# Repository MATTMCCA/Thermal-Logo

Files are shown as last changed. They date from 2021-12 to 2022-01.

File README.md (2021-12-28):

# Thermal Logo Business Card
A business card that "prints" the company logo on thermal paper.

Works with Arduino IDE to allow for easy experimentation. The HW design is based on Adafruit's *itsy bitsy* so I could benefit from there bootloader.

## Now on Rev_2

These Business Cards are not for sale/resale. They are strictly for networking, and **Thermal Printer Shenanigans**. Please do-not misuse the design or business cards, any injury that occurs as a result of malintent or negligence, I am not responsible for. 

#### This device will get hot enough to activate thermal paper, please, *business responsibly*. 

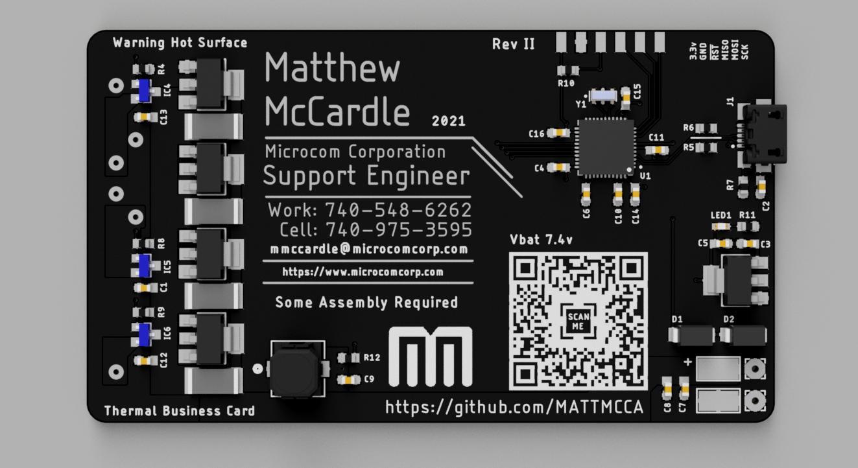
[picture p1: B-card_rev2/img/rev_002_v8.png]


### Borrowed works maintain original license.

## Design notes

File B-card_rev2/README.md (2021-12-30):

# Thermal Logo Business Card
A business card that "prints" the company logo on thermal paper.

# Possible Issues with the Design
- Load resistors might need to be smaller to increase current draw. [piggyback 11's on the vreg channels to get 1.88A, or x2 2.27A, x3 2.72A (*for testing*)]
- IDK if the bootloader I plan on using is compatible with the MCU I nabbed from digikey, I think it will but there is a chance it wont.
- The high current part of the PCB might get a wee bit warm.
- IDK about the switch I picked.
- Still no power switch
- No safety measures in place.
- Publishing my contact details online... not too bright... but oh well.
- My confidence level is 65% (kinda high, its usually only 40%) [Lower Now... 40%, I got cocky]
- **OH WOW!, I should have inverted the QR code.....** [fixed on PCB] 
- **OH WOW!, the usb is wired wrong, so... that stinks...** (I'll just nix the resistors and rewire to test) [fixed on PCB]

### Boards have been sent to fab, two assemblies worth of parts have been ordered.

Parts Came [12/29/2021], just wating on boards.

### Amazon Stuff

[Battery A](https://www.amazon.com/dp/B07DNCK7V2)

[Battery B](https://www.amazon.com/dp/B06ZY6J1P8)

[JST-SM 2-pin](https://www.amazon.com/dp/B01EJI8TQK)

[Fiberglass Tape](https://www.amazon.com/dp/B00823I7B6)

[36 gauge **NiCr** Wire](https://www.amazon.com/dp/B07CHTXZYW)

### Other

[0.4mmm Vias](https://www.voltera.io/store/consumables/rivets-0-4mm)

[Via Set Tool](https://www.voltera.io/store/consumables/rivet-tool)

#### Notes:
You cant really solder **NiCr**, its nickle and chrome, that chemistry would respond better to 'welding'. Since I don't have a tiny spot welder... yet.... I opted for permanent mechanical fasteners. Is this perfect? NO, dose it work? YES!

[Hmmm...](https://www.amazon.com/dp/B093SMWQ2Q) Amazon sells spot welders, might have to get one...

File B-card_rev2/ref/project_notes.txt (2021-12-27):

https://www.kanzan.de/en/products/thermal-papers/thermal-technology/thermal-paper-sensitivity
https://deepblueharp.blogspot.com/2018/04/wire-design-by-jim-whiteside.html#
https://www.printingforless.com/Business-Card-Specifications.html

https://www.amazon.com/TapeCase-134-3-Fiberglass-PTFE-Tape/dp/B00823I7B6
https://www.amazon.com/Nichrome-80-Gauge-Resistance-Wire/dp/B07CHTXZYW

https://www.voltera.io/support/working-with-rivets
https://www.voltera.io/store/consumables/rivets-0-4mm
https://www.voltera.io/store/consumables/rivet-tool

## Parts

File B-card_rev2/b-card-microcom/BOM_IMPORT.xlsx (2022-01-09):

Qty | Value | Device | Package | Parts | Description | DIGI-KEY_PART_NUMBER
8 | 1uF | C-EUC0603 | C0603 | C1, C3, C5, C7, C8, C10, C12, C13 | CAPACITOR, European symbol | 399-3118-1-ND
6 | 100k | R-US_R0603 | R0603 | R4, R7, R8, R9, R10, R12 | RESISTOR, American symbol | RMCF0603FT100KCT-ND
6 | WIREPADSMD1,27-254 | WIREPADSMD1,27-254 | SMD1,27-2,54 | PAD5, PAD6, PAD7, PAD8, PAD9, PAD10 | Wire PAD connect wire on PCB | NOT A REAL PART
4 | 5.6 | R-US_R2512 | R2512 | R1, R2, R3, R13 | RESISTOR, American symbol | CPA25Q5.6CT-ND
4 | AZ1117IH-5.0 | LD117ASTR | SOT223 | IC1, IC2, IC3, IC8 | Low drop fixed and adjustable positive voltage regulators 1 A | AZ1117IH-5.0TRG1DICT-ND
3 | DMN2041L-7 | DS31126 | SOT23 | IC4, IC5, IC6 |  | DMN2041L-7DICT-ND
7 | 0.1uF | C-EUC0603 | C0603 | C2, C9, C14, C15, C16, C6, C4 | CAPACITOR, European symbol | 1276-1006-1-ND
2 | 22 | R-US_R0603 | R0603 | R5, R6 | RESISTOR, American symbol | RMCF0603FT22R0CT-ND
2 | LSM115JE3 | DIODE-DO214BA | DO214BA | D1, D2 | DIODE | LSM115JE3/TR13CT-ND
2 | WIREPAD2,54/0,9 | WIREPAD2,54/0,9 | 2,54/0,9 | PAD2, PAD3 | Wire PAD connect wire on PCB | NOT A REAL PART
2 | WIREPADSMD5-2,5 | WIREPADSMD5-2,5 | 5-2,5 | PAD1, PAD4 | Wire PAD connect wire on PCB | NOT A REAL PART
1 | GREEN | LEDSML0603 | SML0603 | LED1 | LED | 732-12017-1-ND
1 | 10118192-0002LF | 10118192-0002LF | AMPHENOL_10118192-0002LF | J1 | USB - micro B USB 2.0 Receptacle Connector 5 Position Surface Mount, Right Angle | 609-5379-1-ND
1 | 10uF | C-EUC0603 | C0603 | C11 | CAPACITOR, European symbol | 1276-1038-1-ND
1 | 600 | R-US_R0603 | R0603 | R11 | RESISTOR, American symbol | 738-RMCF0603FG604RCT-ND
1 | ATMEGA32U4-MU | ATMEGA32U4-MU | QFN50P700X700X100-45N | U1 | 8-bit Microcontrollers - MCU AVR USB 32K FLASH INDUSTRIA | ATMEGA32U4-MU-ND
1 | AZ1117IH-3.3 | LD117ASTR | SOT223 | IC7 | Low drop fixed and adjustable positive voltage regulators 1 A | AZ1117IH-3.3TRG1DICT-ND
1 | B3AL-1000P | B3AL-1000P | SW_B3AL_OMR | SW1 |  | SW1216CT-ND
1 | CSTNE8M00GH5C000R0 | CSTNE8M00GH5C000R0 | OSC_CSTNE8M00GH5C000R0 | Y1 | 8MHz Ceramic Resonator Built in Capacitor 33pF ±0.13% 40 Ohms -40°C ~ 125°C Surface Mount | 490-17961-1-ND, ALT=50-ECS-CTE-8.00-10-CT-ND
1 | HOT_WIRE | HOT_WIRE | LAYOUT_A | NICR1 |  | NOT A REAL PART

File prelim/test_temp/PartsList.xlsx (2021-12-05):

REF | Val | Part Number | Quantity | Supplier | URL
R1 | 10k | RMCF0603JT10K0CT-ND | 1 | Digikey | https://www.digikey.com/en/products/detail/stackpole-electronics-inc/RMCF0603JT10K0/1758104
R2 | 18 | A121160CT-ND | 1 | Digikey | https://www.digikey.com/en/products/detail/te-connectivity-passive-product/352218RJT/5245011
R3 | 10k | RMCF0603JT10K0CT-ND | 1 | Digikey | https://www.digikey.com/en/products/detail/stackpole-electronics-inc/RMCF0603JT10K0/1758104
R4 | 18 | A121160CT-ND | 1 | Digikey | https://www.digikey.com/en/products/detail/te-connectivity-passive-product/352218RJT/5245011
R5 | 10k | RMCF0603JT10K0CT-ND | 1 | Digikey | https://www.digikey.com/en/products/detail/stackpole-electronics-inc/RMCF0603JT10K0/1758104
R6 | 18 | A121160CT-ND | 1 | Digikey | https://www.digikey.com/en/products/detail/te-connectivity-passive-product/352218RJT/5245011
IC1 | DMN3150 | DMN3150LDICT-ND | 1 | Digikey | https://www.digikey.com/en/products/detail/diodes-incorporated/DMN3150L-7/1774198
IC2 | 74HCS125 | 296-SN74HCS125PWRCT-ND | 1 | Digikey | https://www.digikey.com/en/products/detail/texas-instruments/SN74HCS125PWR/12642216
IC3 | DMN3150 | DMN3150LDICT-ND | 1 | Digikey | https://www.digikey.com/en/products/detail/diodes-incorporated/DMN3150L-7/1774198
IC4 | DMN3150 | DMN3150LDICT-ND | 1 | Digikey | https://www.digikey.com/en/products/detail/diodes-incorporated/DMN3150L-7/1774198
C1 | .1uf | 732-13187-1-ND | 1 | Digikey | https://www.digikey.com/en/products/detail/w%C3%BCrth-elektronik/885382206004/9816342
C2 | .1uf | 732-13187-1-ND | 1 | Digikey | https://www.digikey.com/en/products/detail/w%C3%BCrth-elektronik/885382206004/9816342
SV1 | 8pos header | 1528-2923-ND | 0 | Digikey | https://www.digikey.com/en/products/detail/adafruit-industries-llc/4151/10123802
 | Nichrome 80, 36AWG |  | 1 | amazon | https://www.amazon.com/Nichrome-80-Gauge-Resistance-Wire/dp/B07CHTXZYW
 | PTFE Glass Cloth Tape |  | 1 | amazon | https://www.amazon.com/TapeCase-134-3-Fiberglass-PTFE-Tape/dp/B00823I7B6
 | 0.4mm copper rivets, drill .7mm | 1000283 | 1 | voltera.io | https://www.voltera.io/store/consumables/rivets-0-4mm
 | rivet press tool | 1000288 | 1 | voltera.io | https://www.voltera.io/store/consumables/rivet-tool

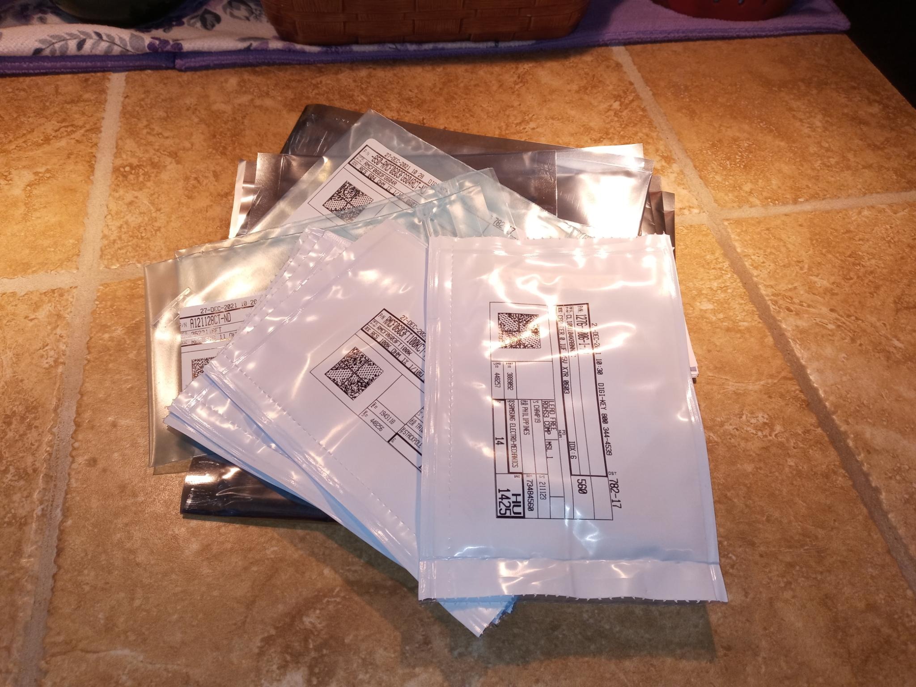
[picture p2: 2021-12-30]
B-card_rev2/img/tests/parts.png

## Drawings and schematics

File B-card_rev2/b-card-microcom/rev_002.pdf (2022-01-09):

# GND +3V³

A

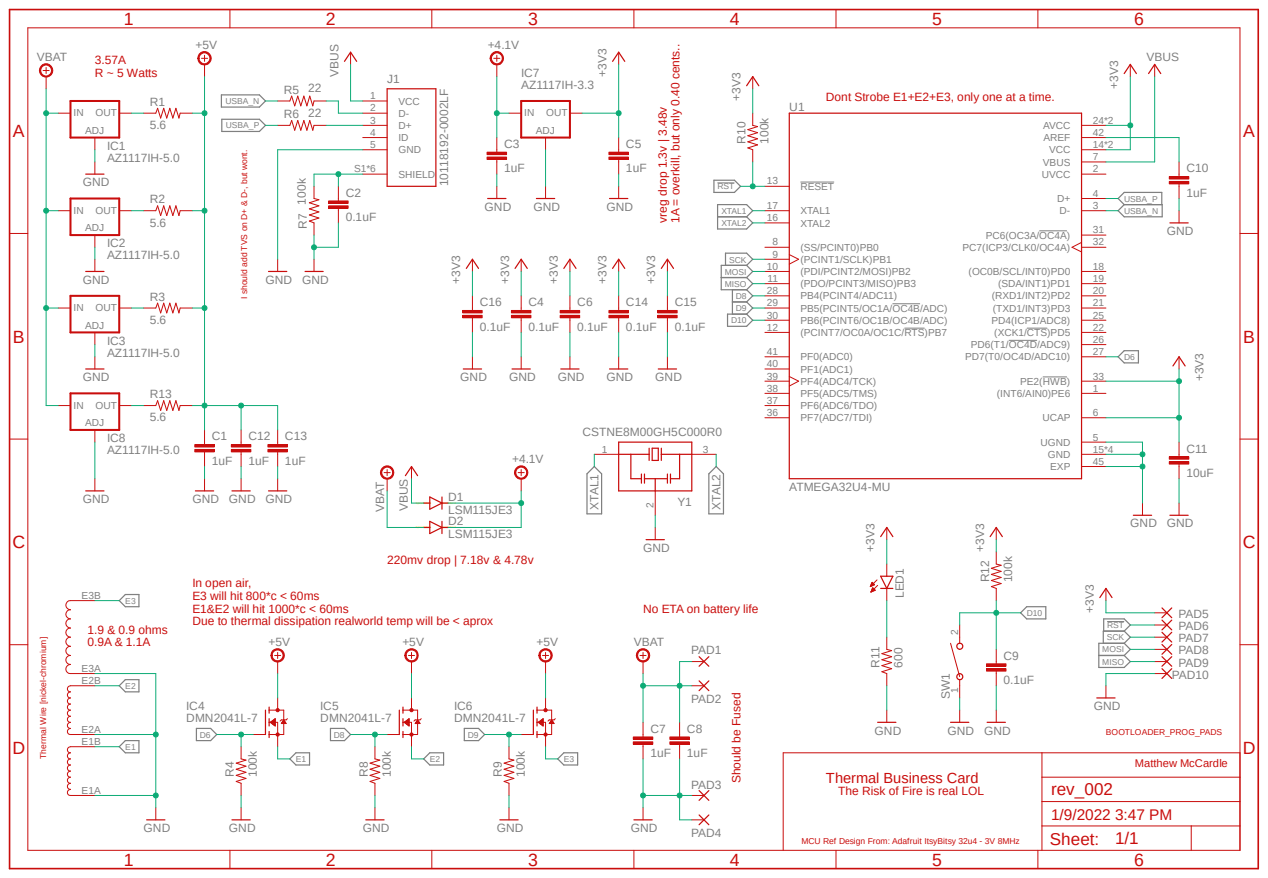
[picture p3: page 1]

Dont Strobe E1+E2+E3, only one at a time.

MCU Ref Design From: Adafruit ItsyBitsy 32u4 - 3V 8MHz I should add TVS on D⁺ & D⁻, but wont.

In open air,
E3 will hit 800*c < 60ms
E1&E2 will hit 1000*c < 60ms
Due to thermal dissipation realworld temp will be < aprox

No ETA on battery life

Matthew McCardle Thermal Wire [nickel-chromium]

Thermal Business Card The Risk of Fire is real LOL

Sheet: 1/1

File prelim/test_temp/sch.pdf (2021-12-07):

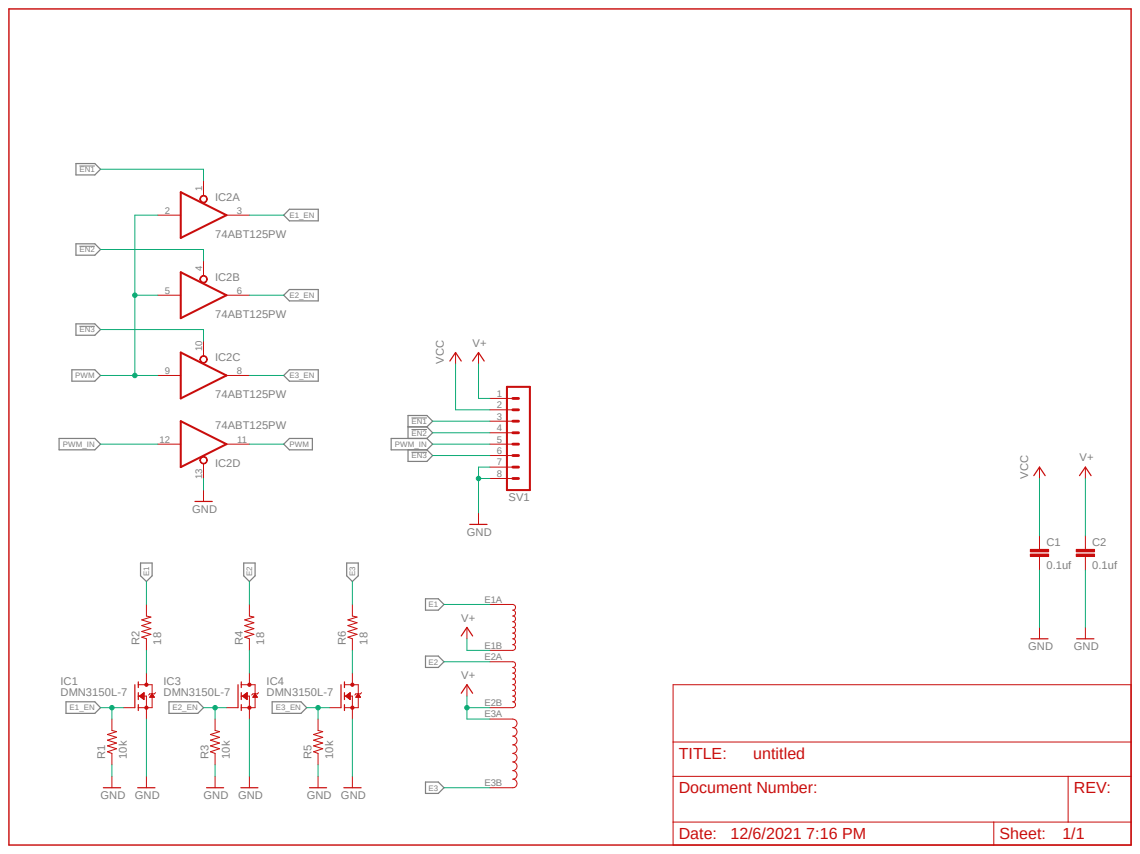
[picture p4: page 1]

Document Number: | REV:

Date: 12/6/2021 7:16 PM | Sheet: 1/1

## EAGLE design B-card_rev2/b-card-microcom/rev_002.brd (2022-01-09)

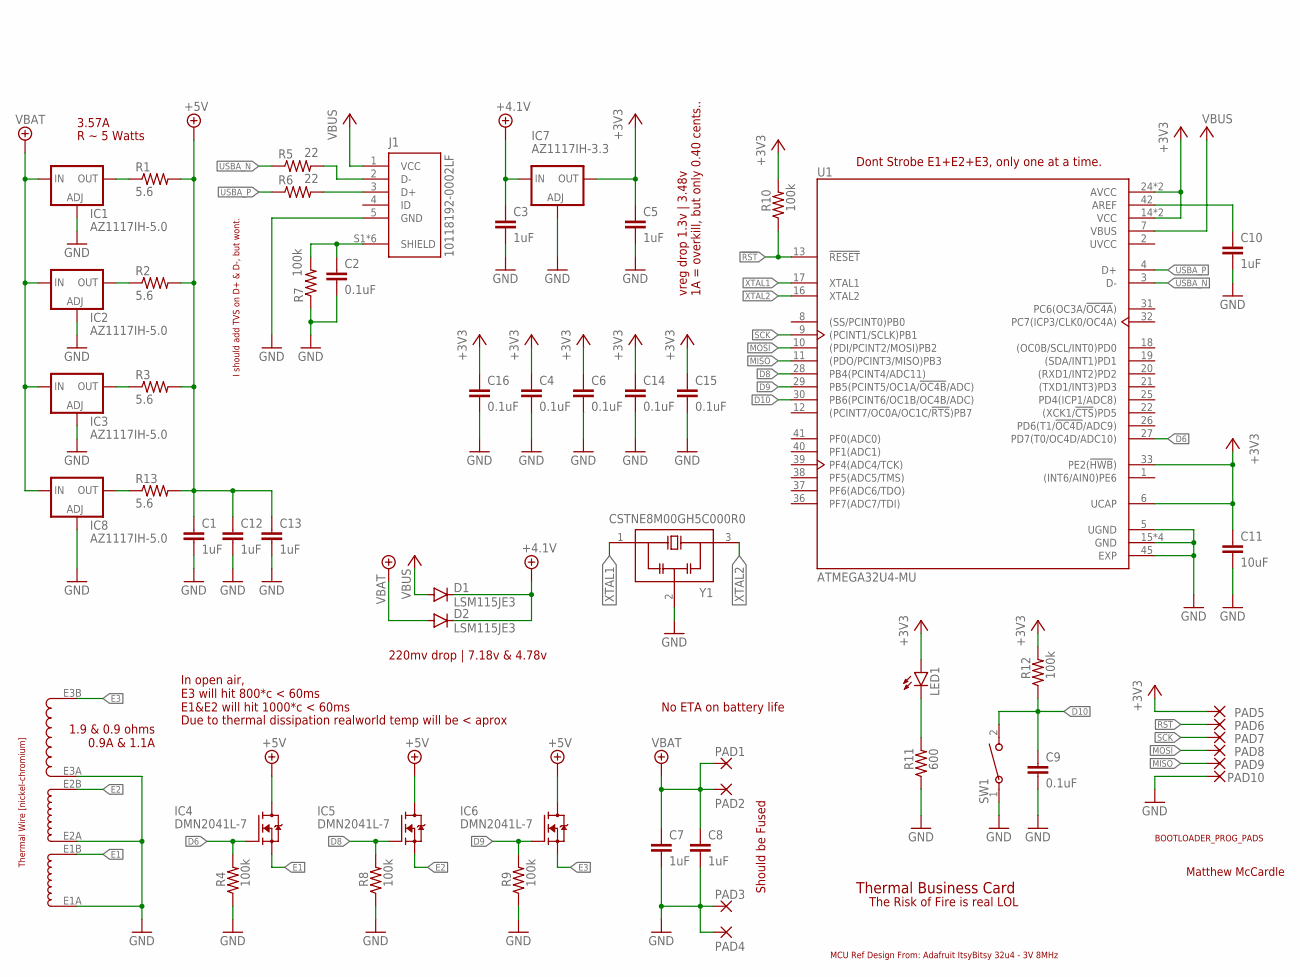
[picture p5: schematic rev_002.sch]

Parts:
C1, C3, C5, C7, C8, C10, C12, C13: 1uF; C0603
C2, C4, C6, C9, C14, C15, C16: 0.1uF; C0603
C11: 10uF; C0603
D1, D2: LSM115JE3; DO214BA
IC1, IC2, IC3, IC8: AZ1117IH-5.0; SOT223
IC4, IC5, IC6: DMN2041L-7; SOT23
IC7: AZ1117IH-3.3; SOT223
J1: 10118192-0002LF; AMPHENOL_10118192-0002LF
LED1: LEDSML0603; SML0603
NICR1: HOT_WIRE; LAYOUT_A
PAD1, PAD4: WIREPADSMD5-2,5; 5-2,5
PAD2, PAD3: WIREPAD2,54/0,9; 2,54/0,9
PAD5, PAD6, PAD7, PAD8, PAD9, PAD10: WIREPADSMD1,27-254; SMD1,27-2,54
R1, R2, R3, R13: 5.6; R2512
R4, R7, R8, R9, R10, R12: 100k; R0603
R5, R6: 22; R0603
R11: 600; R0603
SW1: B3AL-1000P; SW_B3AL_OMR
U1: ATMEGA32U4-MU; QFN50P700X700X100-45N
Y1: CSTNE8M00GH5C000R0; OSC_CSTNE8M00GH5C000R0

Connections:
!RST: PAD6.1, R10.1, U1.13 (!RESET!)
+3V3: C4.1, C5.1, C6.1, C11.1, C14.1, C15.1, C16.1, IC7.2 (OUT), IC7.4 (OUT), LED1.A, PAD5.1, R10.2, R12.2, U1.6 (UCAP), U1.14 (VCC), U1.24 (AVCC), U1.33 (PE2(!HWB!)), U1.34 (VCC), U1.44 (AVCC)
+4.1V: C3.1, D1.C, D2.C, IC7.3 (IN)
+5V: C1.1, C12.1, C13.1, IC4.D, IC5.D, IC6.D, R1.2, R2.2, R3.2, R13.2
+8V: C7.1, C8.1, D2.A, IC1.3 (IN), IC2.3 (IN), IC3.3 (IN), IC8.3 (IN), PAD1.1, PAD2.1
D6: IC4.G, R4.2, U1.27 (PD7(T0/OC4D/ADC10))
D8: IC5.G, R8.2, U1.28 (PB4(PCINT4/ADC11))
D9: IC6.G, R9.2, U1.29 (PB5(PCINT5/OC1A/!OC4B!/ADC))
D10: C9.1, R12.1, SW1.2, U1.30 (PB6(PCINT6/OC1B/OC4B/ADC))
E1: IC4.S, NICR1.E1B
E2: IC5.S, NICR1.E2B
E3: IC6.S, NICR1.E3B
GND: C1.2, C2.2, C3.2, C4.2, C5.2, C6.2, C7.2, C8.2, C9.2, C10.2, C11.2, C12.2, C13.2, C14.2, C15.2, C16.2, IC1.1 (ADJ), IC2.1 (ADJ), IC3.1 (ADJ), IC7.1 (ADJ), IC8.1 (ADJ), J1.5 (GND), NICR1.E1A, NICR1.E2A, NICR1.E3A, PAD3.1, PAD4.1, PAD10.1, R4.1, R7.1, R8.1, R9.1, R11.1, SW1.1, U1.5 (UGND), U1.15 (GND), U1.23 (GND), U1.35 (GND), U1.43 (GND), U1.45 (EXP), Y1.2 (GND)
MISO: PAD9.1, U1.11 ((PDO/PCINT3/MISO)PB3)
MOSI: PAD8.1, U1.10 ((PDI/PCINT2/MOSI)PB2)
unnamed: IC8.2 (OUT), IC8.4 (OUT), R13.1
unnamed: C10.1, U1.42 (AREF)
unnamed: C2.1, J1.S1 (SHIELD), J1.S2 (SHIELD), J1.S3 (SHIELD), J1.S4 (SHIELD), J1.S5 (SHIELD), J1.S6 (SHIELD), R7.2
unnamed: LED1.C, R11.2
unnamed: IC3.2 (OUT), IC3.4 (OUT), R3.1
unnamed: IC2.2 (OUT), IC2.4 (OUT), R2.1
unnamed: IC1.2 (OUT), IC1.4 (OUT), R1.1
SCK: PAD7.1, U1.9 ((PCINT1/SCLK)PB1)
USBA_N: R5.1, U1.3 (D-)
USBA_P: R6.1, U1.4 (D+)
USBB_N: J1.2 (D-), R5.2
USBB_P: J1.3 (D+), R6.2
UVCC: U1.2 (UVCC)
VBUS: D1.A, J1.1 (VCC), U1.7 (VBUS)
XTAL1: U1.17 (XTAL1), Y1.1 (IN)
XTAL2: U1.16 (XTAL2), Y1.3 (OUT)

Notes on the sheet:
MCU Ref Design From: Adafruit ItsyBitsy 32u4 - 3V 8MHz
I should add TVS on D+ & D-, but wont.
BOOTLOADER_PROG_PADS
Matthew McCardle
Thermal Wire [nickel-chromium]
Thermal Business Card
3.57A
R ~ 5 Watts
220mv drop | 7.18v & 4.78v
vreg drop 1.3v | 3.48v 1A = overkill, but only 0.40 cents..
1.9 & 0.9 ohms 0.9A & 1.1A
Should be Fused
In open air, E3 will hit 800*c < 60ms E1&E2 will hit 1000*c < 60ms
Due to thermal dissipation realworld temp will be < aprox
The Risk of Fire is real LOL
Dont Strobe E1+E2+E3, only one at a time.
No ETA on battery life

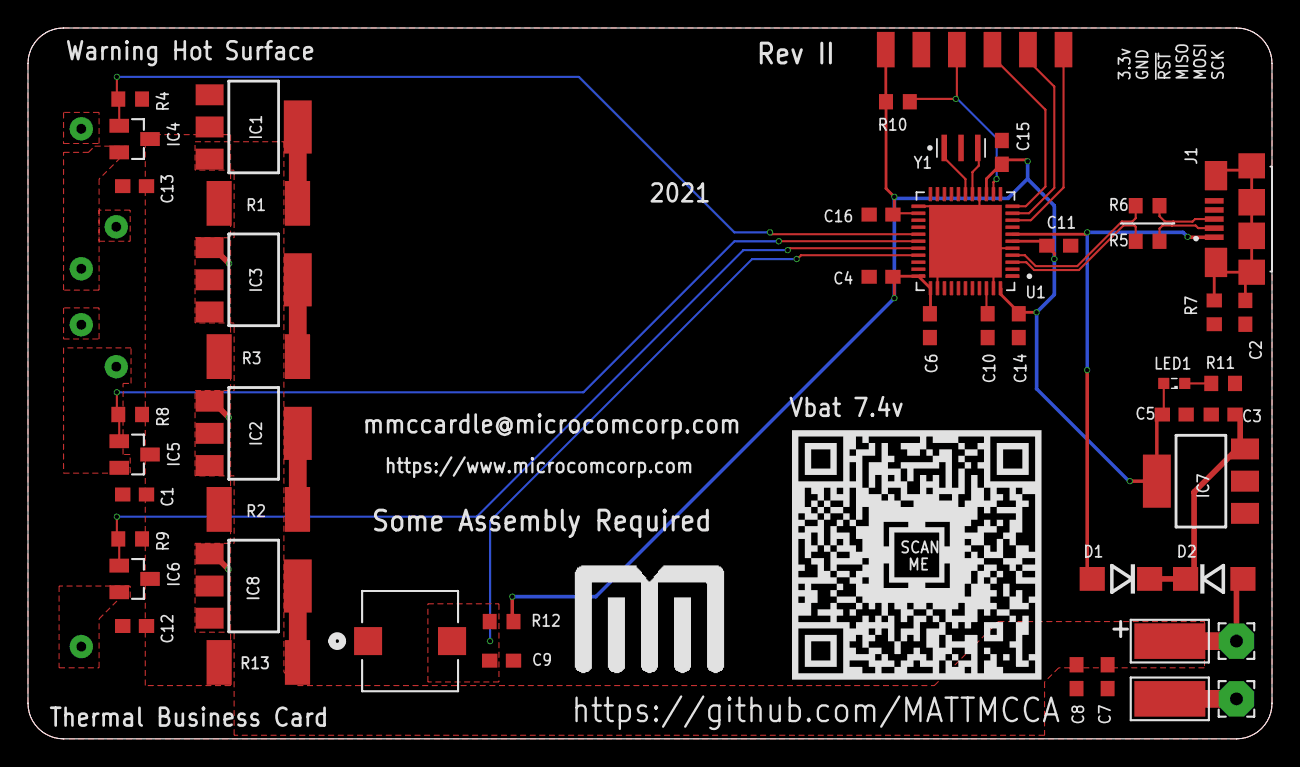
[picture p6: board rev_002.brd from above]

Board: 2 copper layers, 88.9 x 50.8 mm, 57 parts (0 on the bottom side), 30 nets.

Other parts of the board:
U$1: LINK_INV
U$2: MCOM

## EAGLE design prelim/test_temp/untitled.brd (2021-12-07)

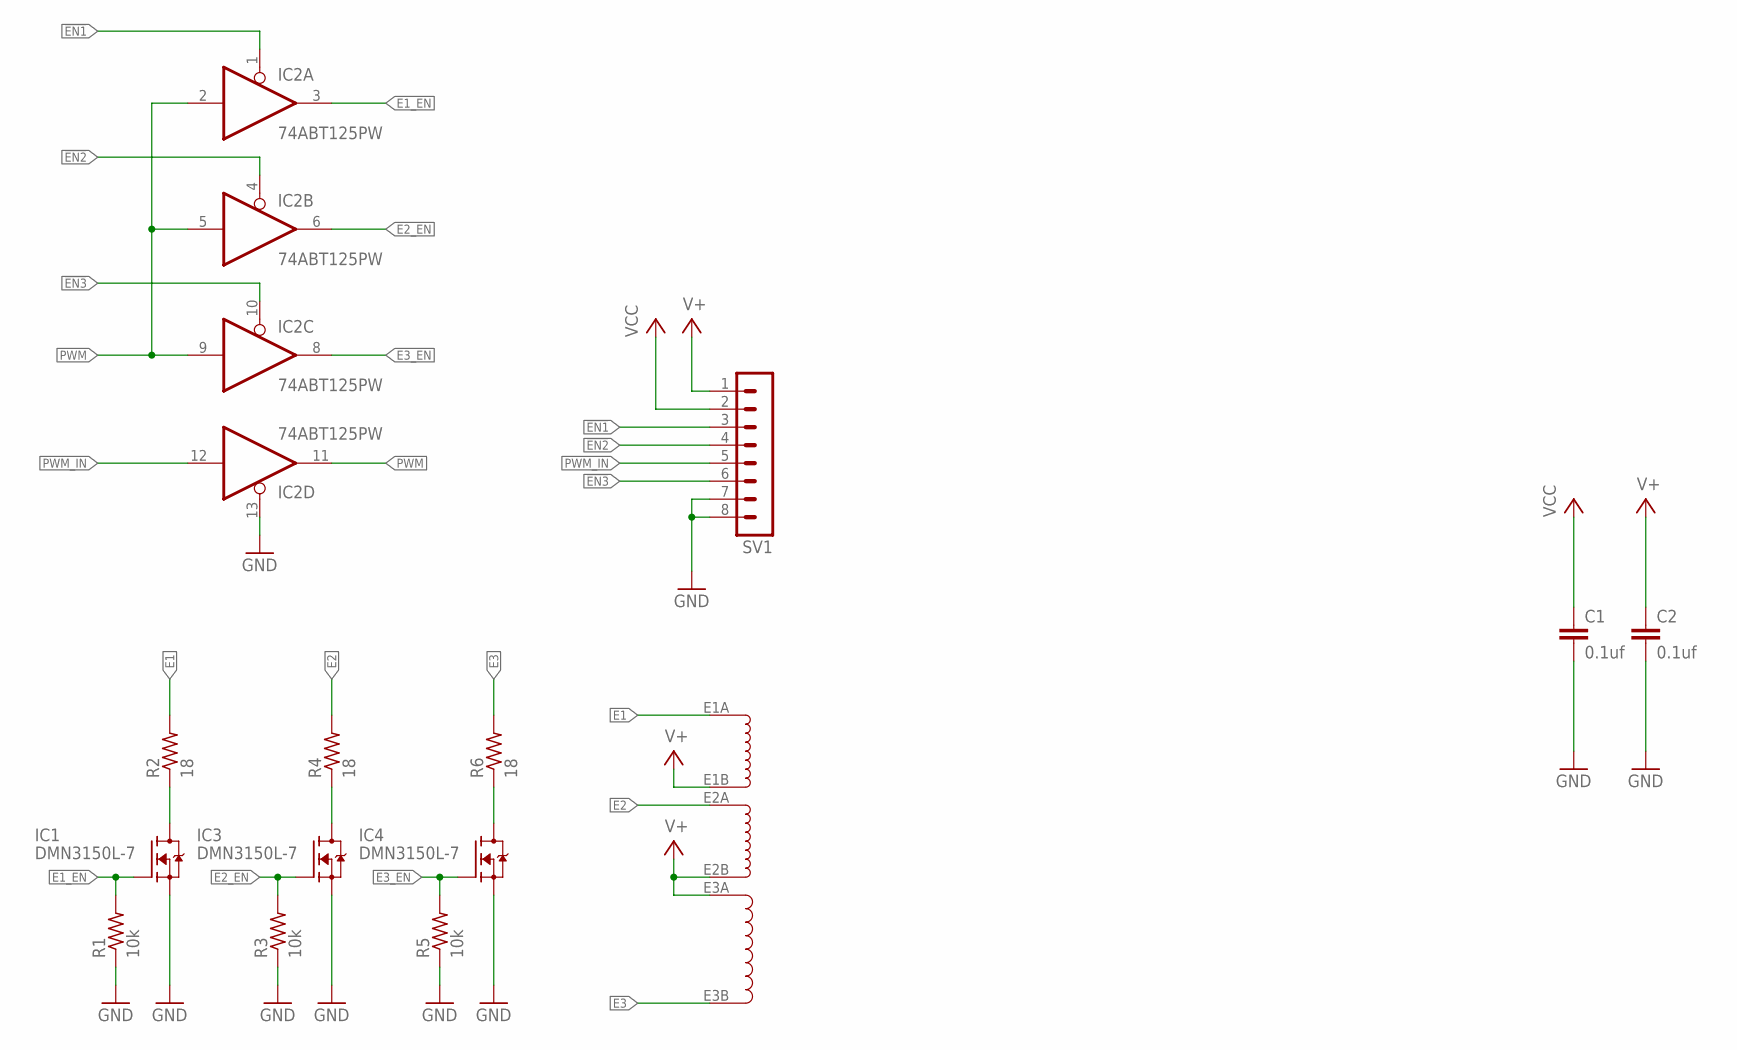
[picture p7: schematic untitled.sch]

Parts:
C1, C2: 0.1uf; C0603
IC1, IC3, IC4: DMN3150L-7; SOT23
IC2: 74ABT125PW; TSSOP14
NICR1: HOT_WIRE; LAYOUT_A
R1, R3, R5: 10k; R0603
R2, R4, R6: 18; R2512W
SV1: MA08-1

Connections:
!EN1: IC2.1 (OE), SV1.3
!EN2: IC2.4 (OE), SV1.4
!EN3: IC2.10 (OE), SV1.6
E1: NICR1.E1A, R2.2
E1_EN: IC1.G, IC2.3 (O), R1.2
E2: NICR1.E2A, R4.2
E2_EN: IC2.6 (O), IC3.G, R3.2
E3: NICR1.E3B, R6.2
E3_EN: IC2.8 (O), IC4.G, R5.2
GND: C1.2, C2.2, IC1.S, IC2.7 (GND), IC2.13 (OE), IC3.S, IC4.S, R1.1, R3.1, R5.1, SV1.7, SV1.8
unnamed: IC1.D, R2.1
unnamed: IC3.D, R4.1
unnamed: IC4.D, R6.1
PWM: IC2.2 (I), IC2.5 (I), IC2.9 (I), IC2.11 (O)
PWM_IN: IC2.12 (I), SV1.5
V+: C2.1, NICR1.E1B, NICR1.E2B, NICR1.E3A, SV1.1
VCC: C1.1, IC2.14 (VCC), SV1.2

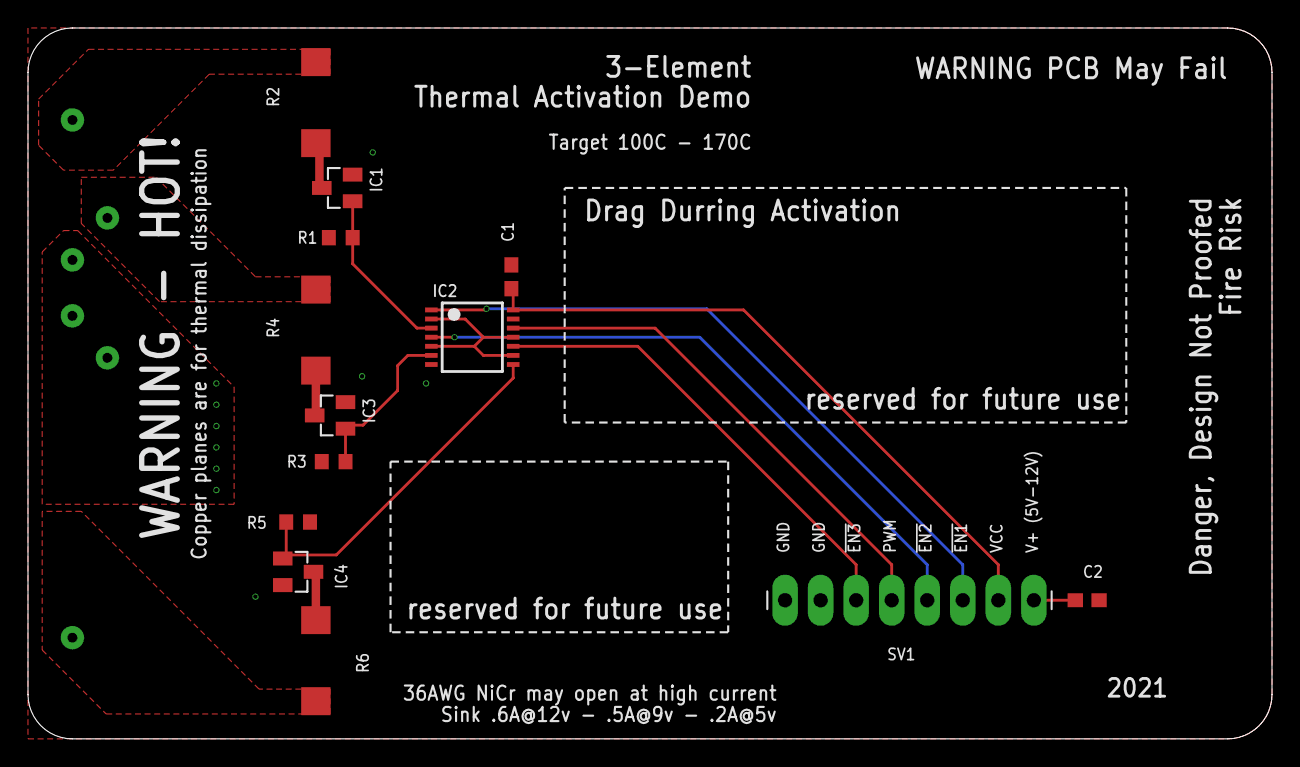
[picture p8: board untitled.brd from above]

Board: 2 copper layers, 88.9 x 50.8 mm, 14 parts (0 on the bottom side), 17 nets.

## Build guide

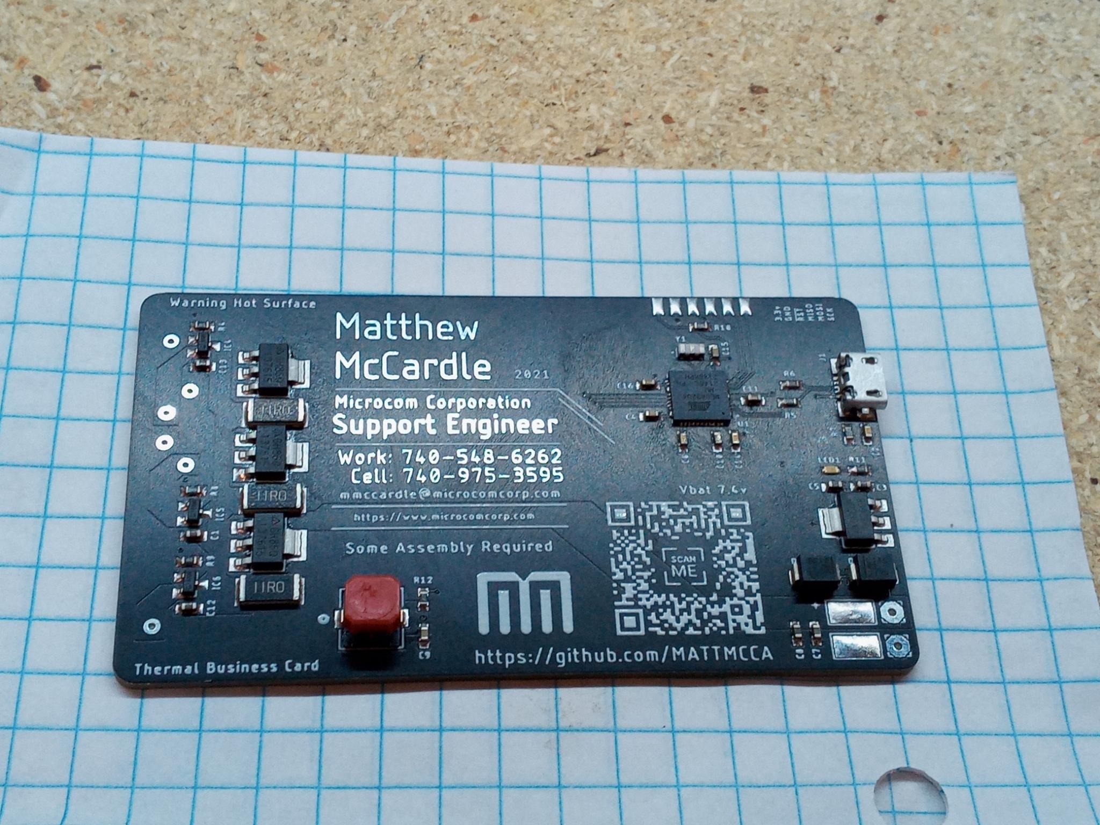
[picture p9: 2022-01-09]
B-card_rev2/img/build_001/002.png

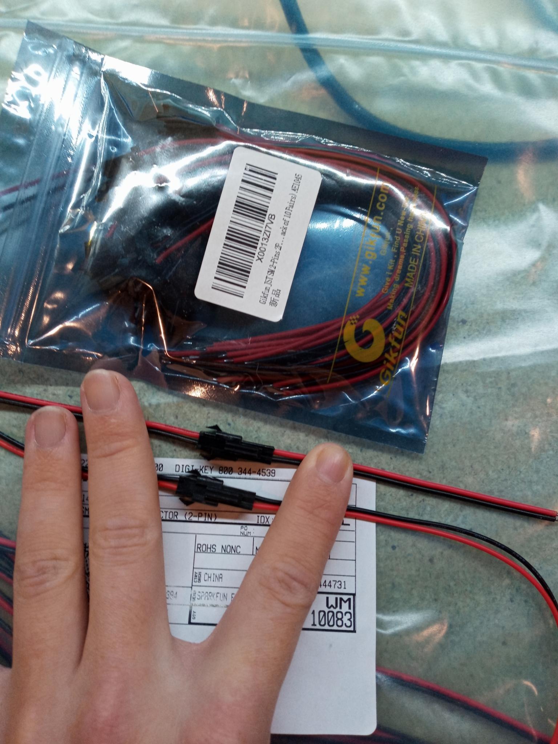
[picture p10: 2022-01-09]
B-card_rev2/img/build_001/004.png

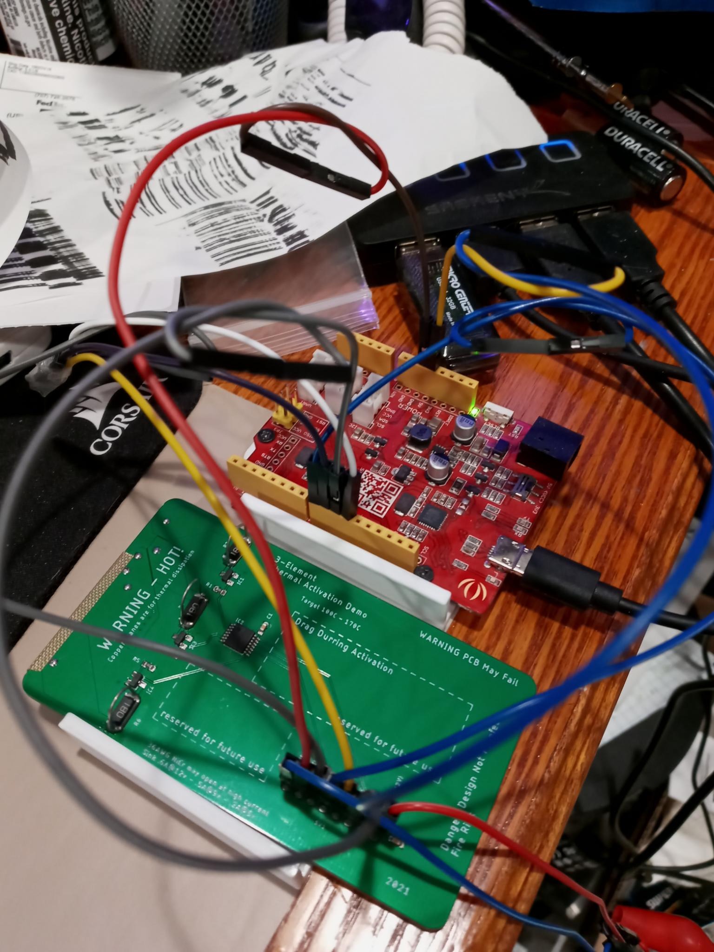
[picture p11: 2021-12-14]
B-card_rev2/img/tests/dirty_bench_setup.png

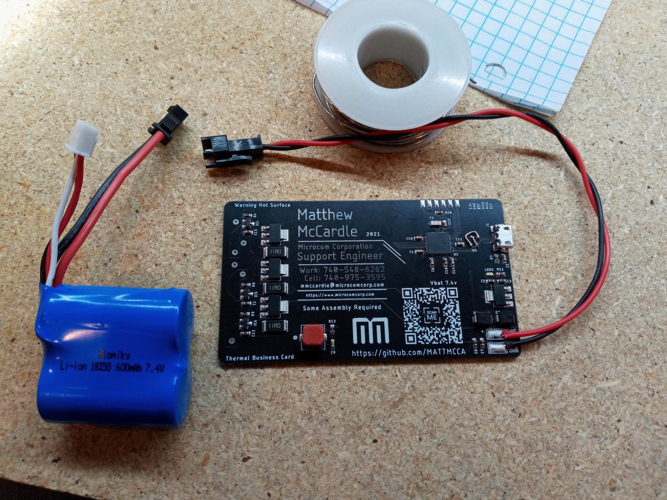
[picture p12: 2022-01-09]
B-card_rev2/img/build_001/001.png

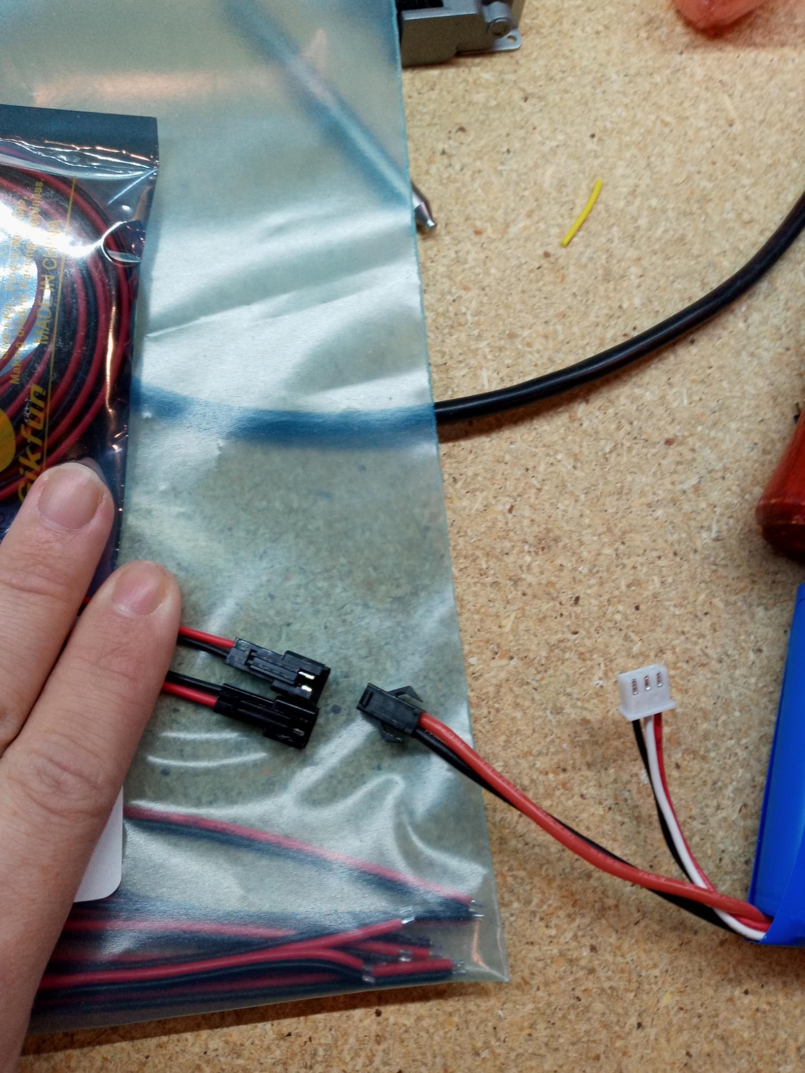
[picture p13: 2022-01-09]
B-card_rev2/img/build_001/003.png

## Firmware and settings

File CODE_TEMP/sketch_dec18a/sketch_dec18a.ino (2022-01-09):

/*
   Thermal Logo Business Card, Board REV_2 (Adafruit Itsy Bitsy 3v 8Mhz)
   MJM - 2021

   Warning! Hardware Will Get HOT!!

   but
      (•_•)
           ( •_•)>⌐■-■
                              (⌐■_■)  the firmware should stay kool.
*/

#define HOT    1
#define COLD   0
#define ACTIVE 0

#define COOL 0
#define HEAT 1

#define E2_OFFSET 4                         /* tune wire offset */

const int micro_pixle = 10;                 /* 20 upix per pix */
const int ms_delay    = 50;                 /* 10ms per E */

/* logo, replaces logic */
const int bmp_size  = 11;
const int bmp[3][bmp_size] = {
  {0, 1, 1, 1, 1, 0, 1, 1, 1, 1, 0},
  {0, 1, 0, 0, 0, 1, 0, 0, 0, 1, 0},
  {0, 1, 0, 1, 0, 1, 0, 1, 0, 1, 0}
};

/* IO deff */
const int TRIGGER = 10;
const int EN_1    = 6;
const int EN_2    = 8;
const int EN_3    = 9;

int SEQ[5][3]      = {
  // E1,   E2,   E3
  {COLD, COLD, COLD}, //state 3, E3
  {COLD, COLD, COLD}, //state 2, E2
  {COLD, COLD, COLD}, //state 3, E3
  {COLD, COLD, COLD}, //state 1, E1
  {COLD, COLD, COLD}  //state 3, E3
};

int cnt = 0, i = 0, e = 0, e2 = 0;

void state_seq(void);
void button_check(void);

void setup() {
  // put your setup code here, to run once:
  pinMode(TRIGGER,      INPUT);
  pinMode(EN_1,         OUTPUT);
  pinMode(EN_2,         OUTPUT);
  pinMode(EN_3,         OUTPUT);
  /****************************************************/
  digitalWrite(EN_1,    COLD); //off
  digitalWrite(EN_2,    COLD); //off
  digitalWrite(EN_3,    COLD); //off
  delay(100);
}

void loop() {
  // put your main code here, to run repeatedly:
  button_check();
  state_seq();

  for (i = 0; i < 5; i++) {
    digitalWrite(EN_1, SEQ[i][0]); /* E1 */
    digitalWrite(EN_2, SEQ[i][1]); /* E2 */
    digitalWrite(EN_3, SEQ[i][2]); /* E3 */
    delay(ms_delay);
  }
  cnt++;
}

void button_check(void) {
  /* loop while !active */
  while (digitalRead(TRIGGER) == !ACTIVE) {
    digitalWrite(EN_3, COLD);
    digitalWrite(EN_2, COLD);
    digitalWrite(EN_1, COLD);
    cnt = 0;
    delay(100); //poll button every ~100ms
  }
}

void state_seq(void) {
  e  = ((cnt)             / micro_pixle) % bmp_size; //mod, prevents out of bounds indexing
  e2 = ((cnt + E2_OFFSET) / micro_pixle) % bmp_size; //mod, prevents out of bounds indexing
  SEQ[3][0] = SEQ[1][1] = SEQ[0][2] = SEQ[2][2] = SEQ[4][2] = COLD;
  /* E1 *************************************************/
  if (bmp[0][e]  == 1)  SEQ[3][0] = HOT;
  /* E2 *************************************************/
  if (bmp[1][e2] == 1)  SEQ[1][1] = HOT;
  /* E3 *************************************************/
  if (bmp[2][e]  == 1)  SEQ[0][2] = SEQ[2][2] = SEQ[4][2] = HOT;
}

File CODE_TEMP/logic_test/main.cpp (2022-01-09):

#include <cstdio>
#include <cstring>

#define HOT    1
#define COLD   0
#define ACTIVE 0

#define COOL 0
#define HEAT 1

#define E2_OFFSET 5                         /* tune wire offset */

const int micro_pixle = 20;                 /* 20 upix per pix */

int THERM_CNT[3]   = {      0,    0,    0};
int     THERM[3]   = {   HEAT, HEAT, HEAT};

int SEQ[3][3]      = {
  // E1,   E2,   E3
  {COLD, COLD, COLD}, //state 1, E1
  {COLD, COLD, COLD}, //state 2, E2
  {COLD, COLD, COLD}  //state 3, E3
};

/* logo, replaces logic */
const int  bmp_size  = 10;
int bmp[3][bmp_size] = {
    {0, 1, 1, 1, 1, 0, 1, 1, 1, 1},
    {0, 1, 0, 0, 0, 1, 0, 0, 0, 1},
    {0, 1, 0, 1, 0, 1, 0, 1, 0, 1}
};

int u_thold = 6; //heat limit, start to cool
int l_thold = 5; //cool, start to heat
int cnt = 0, i = 0, e = 0, e2 = 0;

void state_seq(void);

int main()
{
    printf("LOGO-TEST!: size of %d\n", sizeof(SEQ));
    //return 1;




    int upix_cnt = micro_pixle * bmp_size;
    int E1[upix_cnt] = {0x00};
    int E2[upix_cnt] = {0x00};
    int E3[upix_cnt] = {0x00};

    while(cnt < upix_cnt) {
      state_seq();

      for (i = 0; i < 3; i++) {
        if (SEQ[i][i] == COLD) {
          THERM_CNT[i] = 0;
          THERM[i] = HEAT;
        } else {
          if ((THERM_CNT[i] >= u_thold) && (THERM[i] == HEAT)) THERM[i] = COOL;
          if ((THERM_CNT[i] <= l_thold) && (THERM[i] == COOL)) THERM[i] = HEAT;
          if (THERM[i] == HEAT)                                THERM_CNT[i]++;
          else                                                 THERM_CNT[i]--;
        }
      }

      E1[cnt] = SEQ[0][0] & THERM[0];
      E2[cnt] = SEQ[1][1] & THERM[1];
      E3[cnt] = SEQ[2][2] & THERM[2];
      cnt++;
    }

    //display for visual inspection
    int *g[3] = {(int*)&E1, (int*)&E2, (int*)&E3};
    for(int j = 0; j < 3; j++) {
        int l = micro_pixle/2;
        if(j == 2 ) l*=3;
        for(int b = 0; b < l; b++) {
            printf("E%d: ", j+1);
            int *h = g[j];
            for(int u = 0; u < upix_cnt; u++) {
                if(h[u] == 1) printf("#");
                else          printf(".");
            }
            printf("\n");
        }
    }
    return 0;
}

/* WORK LOGO LOGIC */
void state_seq(void) {
  e = ((cnt)              / micro_pixle) % bmp_size; //mod prevent out of bounds indexing
  e2 = ((cnt + E2_OFFSET) / micro_pixle) % bmp_size; //mod prevent out of bounds indexing
  SEQ[0][0] = SEQ[1][1] = SEQ[2][2] = COLD;
  /* E1 *************************************************/
  if(bmp[0][e] == 1)  SEQ[0][0] = HOT;
  /* E2 *************************************************/
  if(bmp[1][e2] == 1) SEQ[1][1] = HOT;
  /* E3 *************************************************/
  if(bmp[2][e] == 1)  SEQ[2][2] = HOT;
}



//100

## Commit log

2021-12-05 sent to fab + parts on order
    if this works ill be surprised. it should... but man, I see alot is issues. *fingers crossed*
    [PartsList.xlsx, untitled.brd, untitled.sch]
2021-12-07 fixed sch
    [untitled.brd, untitled.sch]
2021-12-12 img of PCB
    PCB's from JLC, populated + wire set with Via's
2021-12-14 test img + code
    Power supply was limited at 5V@2A during test.
2021-12-18 wip
    work in progress, not very confident in the design at the moment.
    Charging a 2ah batt @ 500ma will take like 4 hours.
    now sure how low the voltage will sag during operation, the risk of brownout is real.
    still need to add a crystal, smd not can.
    JST connector is only rated for 2A, I don't think it will melt, but its out of spec.
    + other issues
    [rev_001.brd, rev_001.sch]
2021-12-19 need sleep, 2Bcont
    [rev_001.brd, rev_001.sch]
2021-12-26 rev 2
    still not working, builder be warned.
    [rev_002.brd, rev_002.sch]
2021-12-26 update
    this should work, Kinda feel like i should be pushing more current though the elements, but its rev 2, we will see.
    Vreg & resistors should stay below the thermal limit. The only thing that should get hot is the activation wire..... mfets should stay cool too i hope.
    [rev_002.brd, rev_002.sch]
2021-12-27 layout kinda done
    I'm not 100% happy with everything yet, but it looks like it could work.
    [rev_002.brd, rev_002.sch]
2021-12-27 rev 2 90% done
    I need to give everything a once over before fab, and throw together a parts list.
    [rev_002.brd]
2021-12-28 Inverted QR
    QR looks like poo, I may thin it out.
    [rev_002.brd]
2021-12-31 removed logic
    replaced logic with bitmap & offset value
    [main.cpp, sketch_dec18a.ino]
2022-01-09 not rev-ed
    Changed the sch and board, adapted for higher current.
    Made small change to sketch, removed thermal approx.
    exported new Gerber's.
    changed BOM to reflect new design.
    layout change now ready for fab, still needs a once over to correct any mistakes that I may have missed.
    [BOM_IMPORT.xlsx, rev_002.brd, rev_002.sch]

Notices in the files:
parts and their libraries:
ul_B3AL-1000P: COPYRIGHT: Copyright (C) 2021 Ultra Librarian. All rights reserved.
